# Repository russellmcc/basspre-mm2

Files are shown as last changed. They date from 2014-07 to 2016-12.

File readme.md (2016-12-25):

# Basspre MM2

This is an open-source bass pre-amp meant for internal use in active basses with humbucker
inputs.  The circuit is a tribute to the classic 2-band pre-amp used in the
original MusicMan Stingray, with a few modifications.

Board layout and schematic files are in EAGLE format, while the simulations are
done in LT-SPICE.

The pre-amp has a buffered input to maintain very low thermal noise, it uses a rail-splitter IC
instead of a resistor divider to ensure clean tone with very low power, and
the voicing is modified to be less treble-heavy to ensure low EM interference.

[PDF Schematic](schem.pdf)

[OSH Park Link](https://oshpark.com/shared_projects/A13YAxJk)

Here's some simulations and tests of the voicing at various pot positions:

## Flat

### Simulation

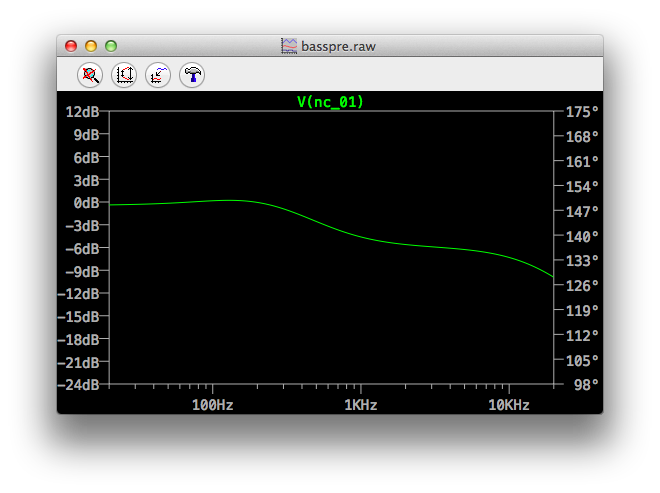
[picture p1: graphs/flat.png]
flat


## Bass Cut

### Simulation

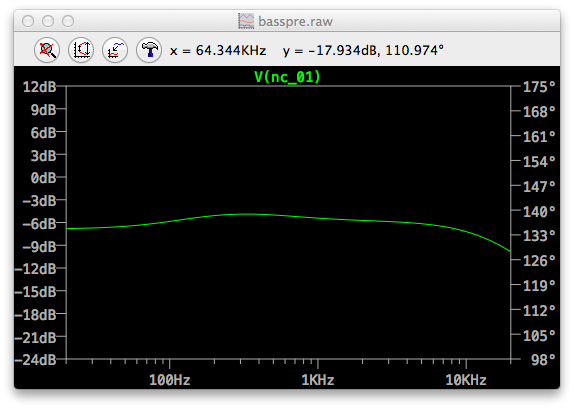
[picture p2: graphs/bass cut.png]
bass cut


## Bass Boost

### Simulation

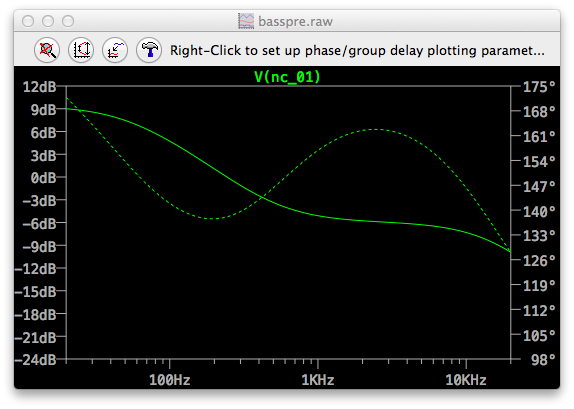
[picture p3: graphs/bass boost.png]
bass boost


### Test

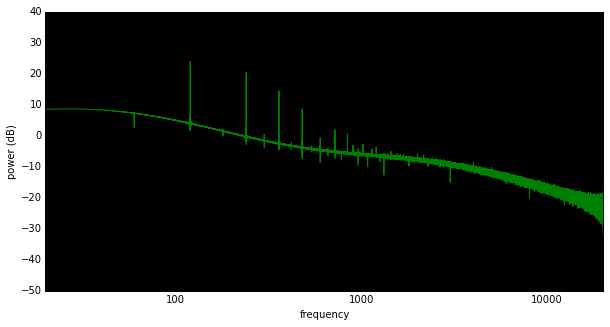
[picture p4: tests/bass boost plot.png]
bass boost


## Treble Cut

### Simulation

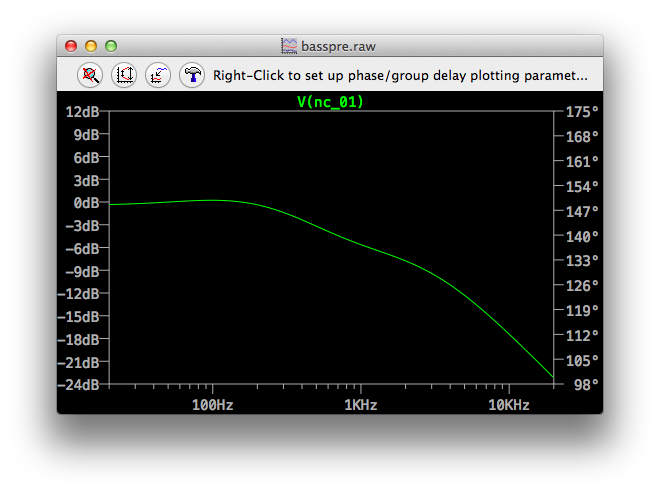
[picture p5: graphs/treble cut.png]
treble cut


## Treble Boost

### Simulation

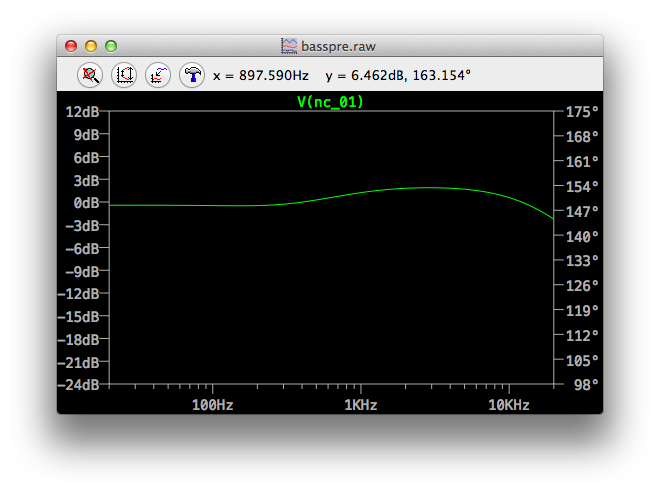
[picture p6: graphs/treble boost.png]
treble boost


### Test

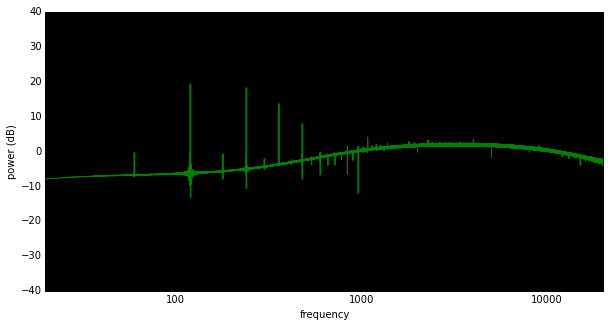
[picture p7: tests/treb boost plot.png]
treble boost


## Both Boost

### Simulation

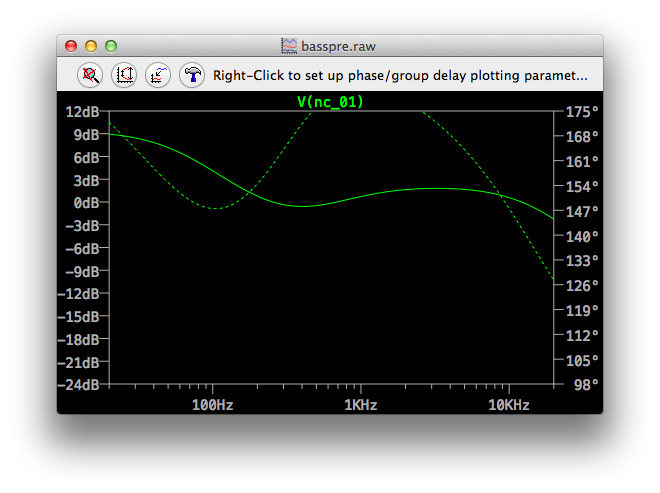
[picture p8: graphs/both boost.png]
both boost


### Test

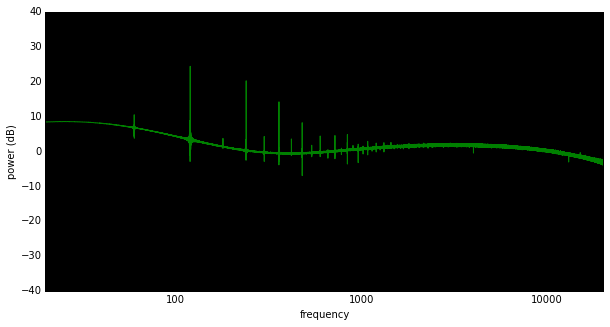
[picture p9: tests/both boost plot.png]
both boost


## Both Cut

### Simulation

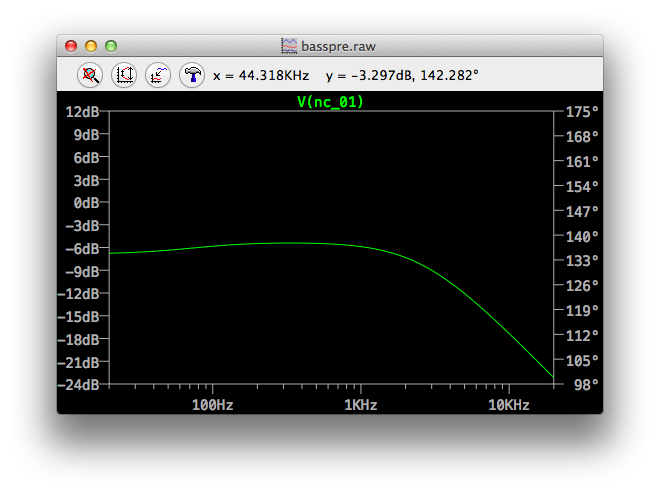
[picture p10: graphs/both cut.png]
both cut


### Test

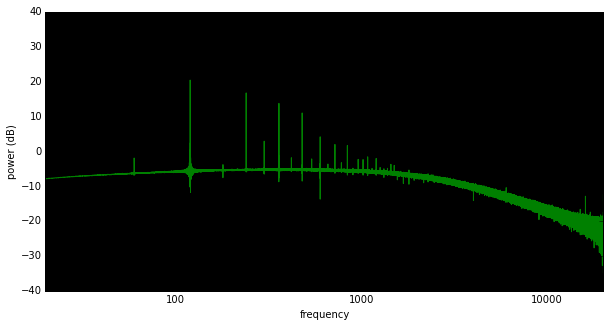
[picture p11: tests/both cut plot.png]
both cut


Copyright 2014, Russell McClellan, all rights reserved.

<br /><span xmlns:dct="http://purl.org/dc/terms/" property="dct:title">Basspre MM-2</span> by <a xmlns:cc="http://creativecommons.org/ns#" href="russellmcc.com" property="cc:attributionName" rel="cc:attributionURL">Russell McClellan</a> is licensed under a <a rel="license" href="http://creativecommons.org/licenses/by-sa/4.0/">Creative Commons Attribution-ShareAlike 4.0 International License</a>.

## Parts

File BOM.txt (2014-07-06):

Capacitors
1x 0603 120pF C0G 5% (C105)
1x 0603 470pF C0G 5% (C106)
1x 0603 1800pF C0G 5% (C103)
1x 0603 47nF X7R 10% (C108)
4x 0603 .1uF X7R 10% (C201, C202, C203, C204)
3x 0805 1uF X7R 10% (C101, C102, C107)
1x 0805 10uF 10V X5R 10% (C109)

Resistors
1x 0603 10K 1% (R105)
2x 0603 100K 1% (R103, R106)
1x 0603 220K 1% (R102)
3x 0603 1.5M 5% (R101, R104, R107)

Connectors
1x 10x1 pin .1 inch header (for easy hook-up - optional)
10x jumper wire (for easy hook-up - optional)

ICs
1x SOIC-8 TLE2426 rail splitter
2x SOIC-8 LM4250 op amp

Potentiometers
1x 25K log (volume)
1x 50K log (bass) (10K is flat, 0 is cut, 50K is boost)
1x 1M reverse log (treble) (Treble1-2: 500K is flat, 0 is cut, 1M is boost)

Link to mouser order (DOES NOT INCLUDE POTS - choose pots that work for you!)
https://www.mouser.com/ProjectManager/ProjectDetail.aspx?AccessID=39f156a9a5

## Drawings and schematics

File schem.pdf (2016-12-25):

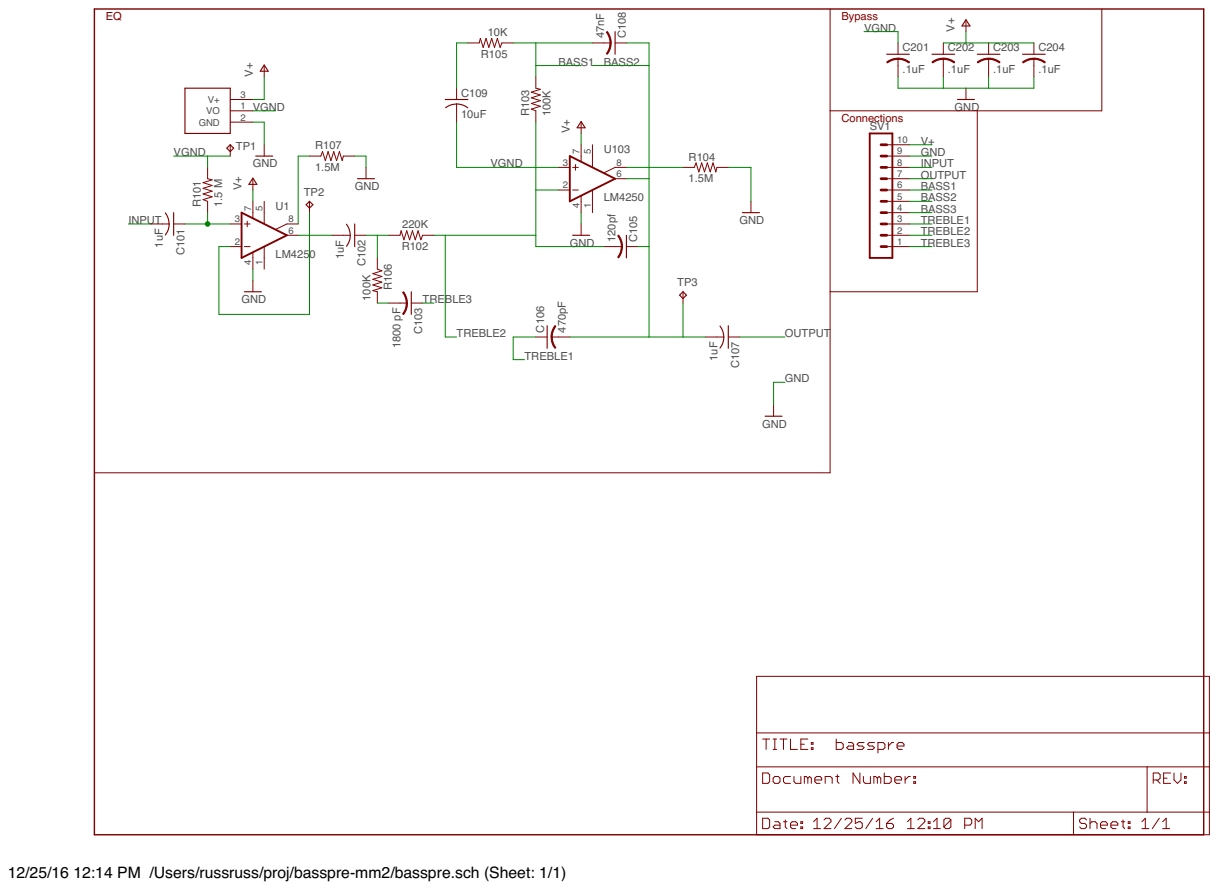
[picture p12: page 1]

12/25/16 12:14 PM /Users/russruss/proj/basspre-mm2/basspre.sch (Sheet: 1/1)

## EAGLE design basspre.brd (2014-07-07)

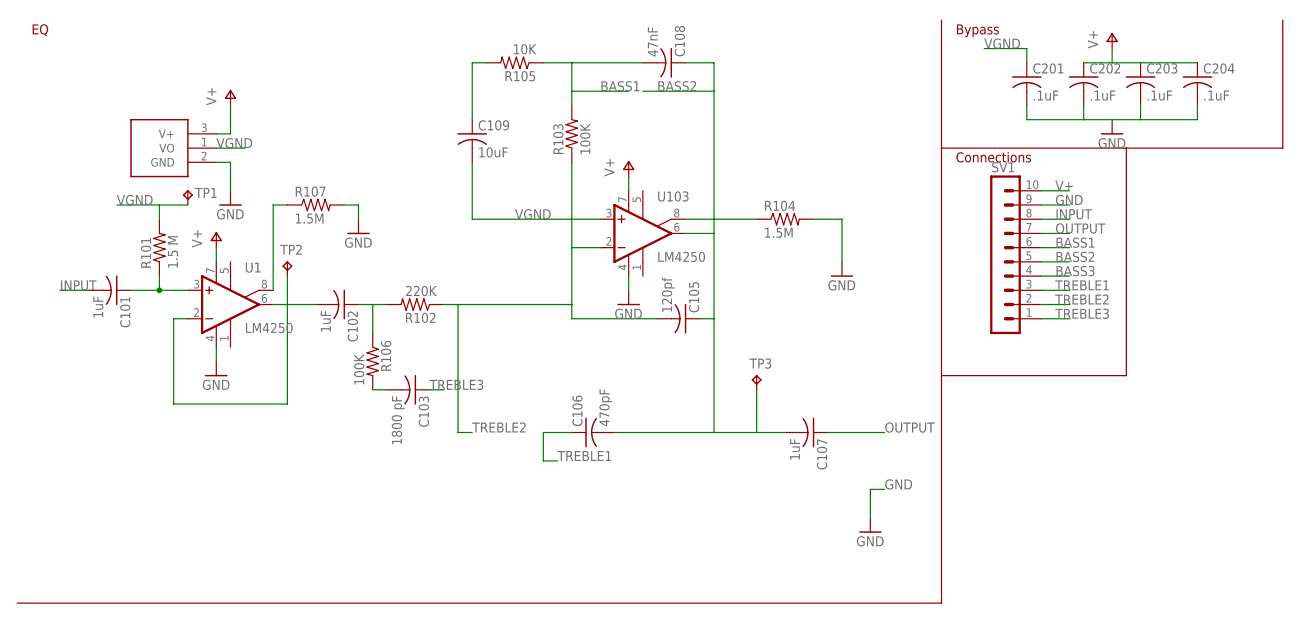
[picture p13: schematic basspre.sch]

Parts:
C101, C102, C107: 1uF; C0805
C103: 1800 pF; C0603
C105: 120pf; C0603
C106: 470pF; C0603
C108: 47nF; C0603
C109: 10uF; C0805
C201, C202, C203, C204: .1uF; C0603
R101: 1.5 M; R0603
R102: 220K; R0603
R103, R106: 100K; R0603
R104, R107: 1.5M; R0603
R105: 10K; R0603
SV1: MA10-1
TP1, TP2, TP3: TPPAD1-13; P1-13
U1, U103: LM4250; SOIC8
U101: TLE2426IDR; SOIC8

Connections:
BASS1: C108.2, R103.2, R105.1, SV1.6
BASS2: C105.1, C106.2, C107.2, C108.1, SV1.5, TP3.TP, U103.6 (OUT)
BASS3: SV1.4
C1: C101.1, R101.1, U1.3 (+IN)
GND: C201.2, C202.2, C203.2, C204.2, R104.2, R107.2, SV1.9, U1.4 (V-), U101.2 (GND), U103.4 (V-)
INPUT: C101.2, SV1.8
unnamed: C102.1, R102.2, R106.1
unnamed: R104.1, U103.8 (CURRENT)
unnamed: C102.2, TP2.TP, U1.2 (-IN), U1.6 (OUT)
unnamed: C109.1, R105.2
unnamed: C103.2, R106.2
OUTPUT: C107.1, SV1.7
R107: R107.1, U1.8 (CURRENT)
TREBLE1: C106.1, SV1.3
TREBLE2: C105.2, R102.1, R103.1, SV1.2, U103.2 (-IN)
TREBLE3: C103.1, SV1.1
V+: C202.1, C203.1, C204.1, SV1.10, U1.7 (V+), U101.3 (V+), U103.7 (V+)
VGND: C109.2, C201.1, R101.2, TP1.TP, U101.1 (VO), U103.3 (+IN)

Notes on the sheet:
Bypass
Connections

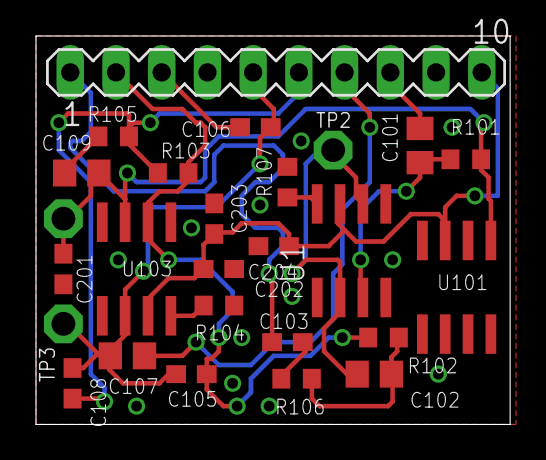
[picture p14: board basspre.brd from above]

Board: 2 copper layers, 26.3 x 21.6 mm, 27 parts (1 on the bottom side), 17 nets.

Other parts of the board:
U$1: OSHW-LOGO-L

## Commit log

2014-06-23 minimal work
    [basspre.sch]
2014-07-05 initial layout
    [basspre.brd, basspre.sch]
2014-07-05 added silkscreen started (rough) sim
    [basspre.brd]
2014-07-05 fix up values
    [basspre.brd, basspre.sch]
2014-07-06 added simulations, changed some values around
    [basspre.brd, basspre.sch]
2014-07-06 switched to 10 pin system so bass pot can be three terminal in future revisions without changing connection.
    [basspre.brd, basspre.sch]
2014-07-06 switched to two lm4250s for micropower operation, added readme
    [basspre.brd, basspre.sch]
2014-07-06 changed bypass caps to 0805.
    [basspre.brd, basspre.sch]
2014-07-06 added mouser order
    [basspre.brd, basspre.sch]
2014-07-07 tent all the vias
    [basspre.brd]
2014-07-07 redid layout to be smaller
    [basspre.brd]
2014-07-07 added labeling silkscreens
    [basspre.brd]
2016-12-25 Add Schematic PDF

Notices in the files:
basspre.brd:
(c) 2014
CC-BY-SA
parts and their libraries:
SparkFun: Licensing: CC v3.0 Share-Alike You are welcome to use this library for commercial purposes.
